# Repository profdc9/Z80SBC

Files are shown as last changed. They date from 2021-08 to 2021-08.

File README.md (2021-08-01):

# Z80 Single Board Computer

This is a PCB layout by Daniel Marks of Grant Searle's 9 chip CP/M computer as obtained from

http://searle.x10host.com/cpm/index.html

You need to follow his instructions on how to flash the memory and install CP/M.

http://searle.x10host.com/cpm/z80sbcFiles.zip

This design uses a 28C256 (32k X 8 EEPROM) rather than the original 27128 (16 x 8 EPROM).  JP6 needs to be set to the 16K setting, and only the first 16K of the EEPROM needs to be programmed.

I have added a 8255A peripheral interface and a SPI serial peripheral interface port.  I plan on modifying the SD card driver to use the faster hardware on this board, using the SD card loader here:

http://xepb.org/dtz/sgsbcsd.html

The SPI peripheral will hopefully allow other hardware to be easily added such as an ethernet interface (Wiznet or enc28j60) for TCP/IP, a SPI LCD for display, etc.  JP2 selects the clockspeed of the SPI, either 1/2 of 7.3278 MHz (slow clock) or 16 MHz (fast clock).

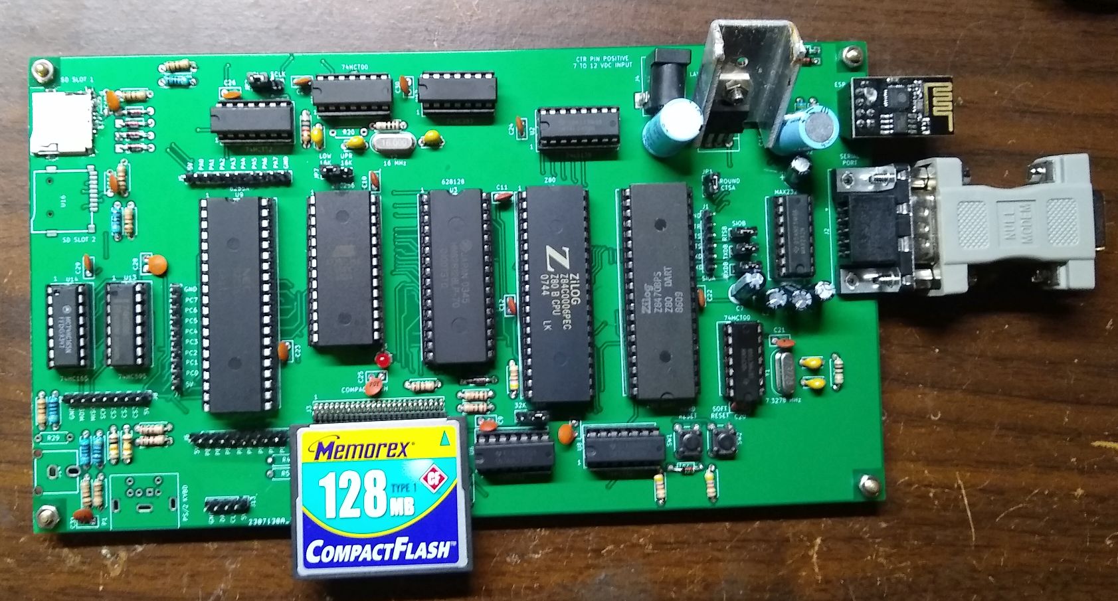
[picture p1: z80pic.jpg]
PCBphoto


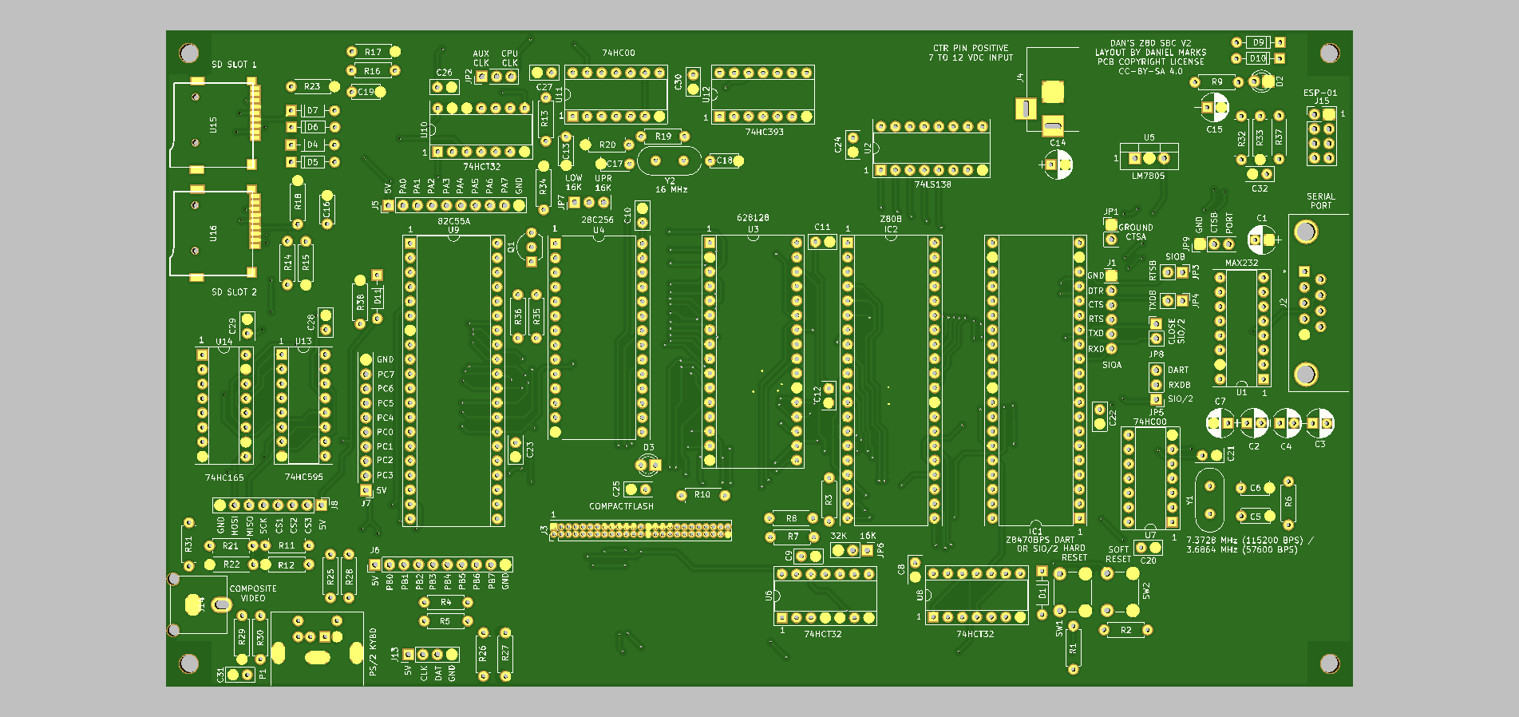
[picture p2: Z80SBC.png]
PCB


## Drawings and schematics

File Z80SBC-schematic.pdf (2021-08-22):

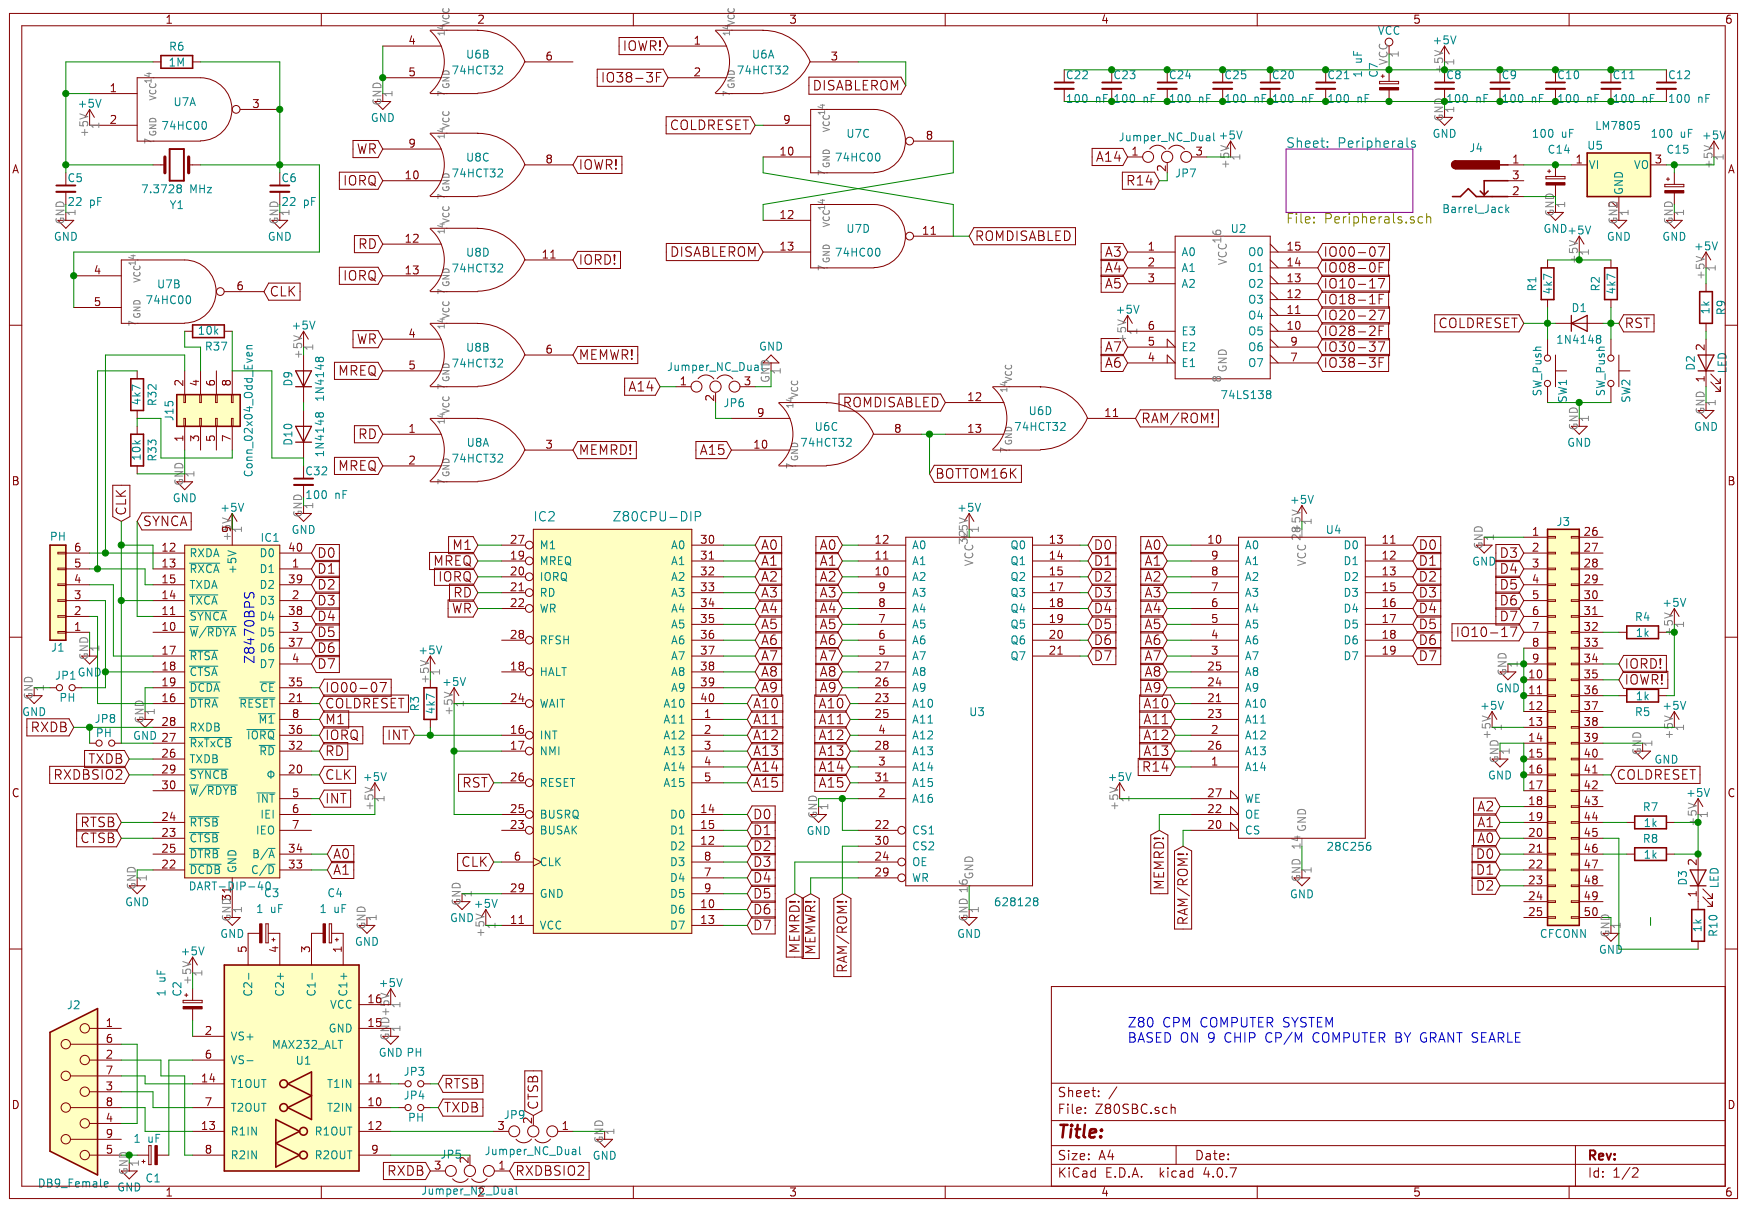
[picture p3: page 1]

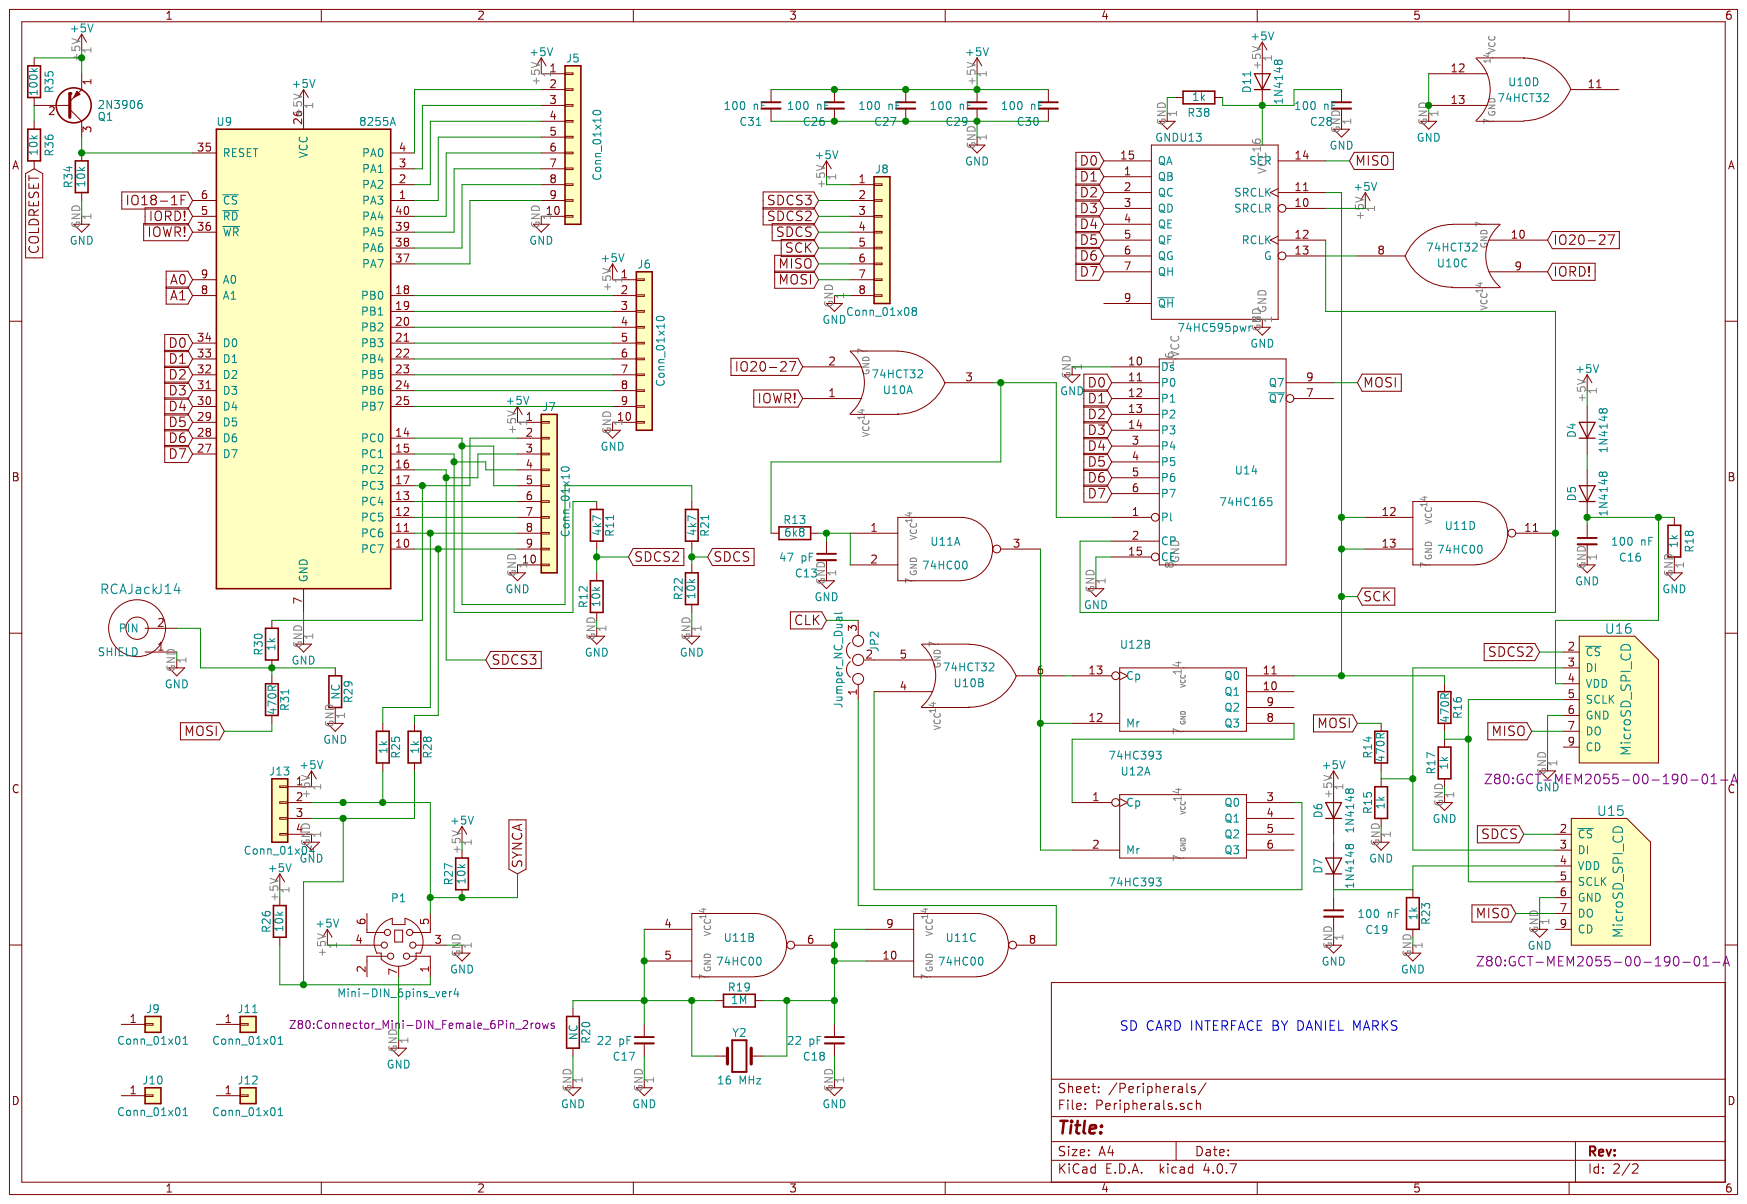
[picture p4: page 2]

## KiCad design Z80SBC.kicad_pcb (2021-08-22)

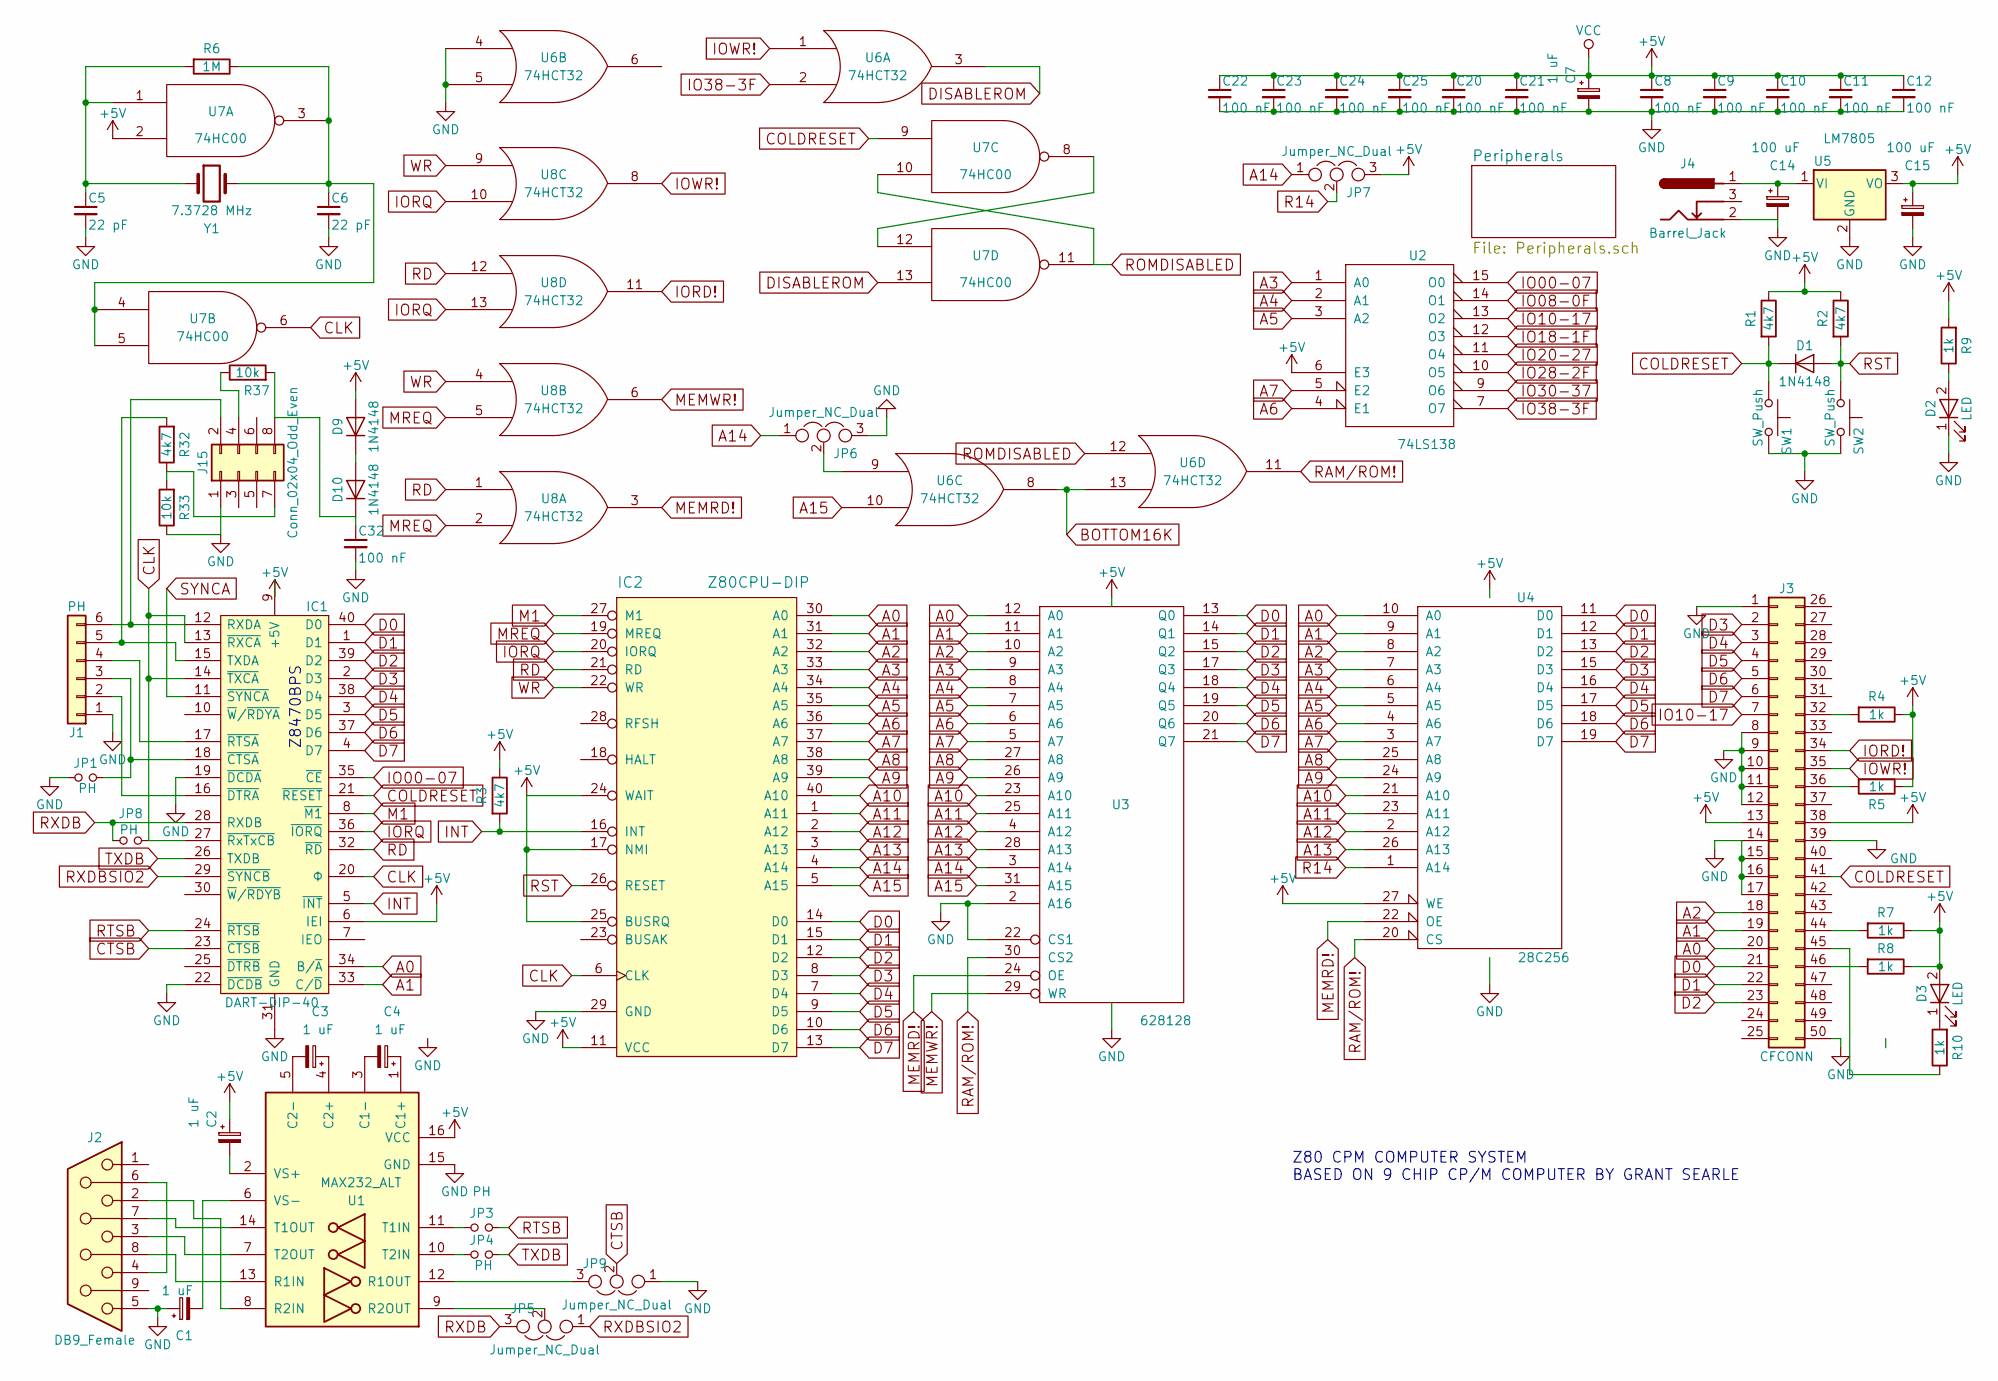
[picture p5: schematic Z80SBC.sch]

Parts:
C1, C2, C3, C4, C7: 1 uF; CP_Radial_D5.0mm_P2.50mm
C5, C6: 22 pF; C_Disc_D5.0mm_W2.5mm_P5.00mm
C8, C9, C10, C11, C12, C20, C21, C22, C23, C24, C25, C32: 100 nF; C_Disc_D5.0mm_W2.5mm_P2.50mm
C14, C15: 100 uF; CP_Radial_D5.0mm_P2.50mm
D1, D9, D10: 1N4148; D_DO-35_SOD27_P7.62mm_Horizontal
D2, D3: LED; LED_D3.0mm
IC1: DART-DIP-40; DIP-40_W15.24mm_Socket; Manufacturer_Part_Number Z84C4206PEG; Mouser Part Number 692-Z84C4206PEG
IC2: Z80CPU-DIP; DIP-40_W15.24mm_Socket
J1: PH; Pin_Header_Straight_1x06_Pitch2.54mm
J2: DB9_Female; DSUB-9_Female_Horizontal_P2.77x2.84mm_EdgePinOffset4.94mm_H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
J3: CFCONN; Pin_Header_Straight_2x25_Pitch1.27mm_Rev
J4: Barrel_Jack; BARREL_JACK
J15: Conn_02x04_Odd_Even; Pin_Header_Straight_2x04_Pitch2.54mm_Flipped
JP1, JP3, JP4, JP8: PH; Pin_Header_Straight_1x02_Pitch2.54mm
JP5, JP6, JP7, JP9: Jumper_NC_Dual; Pin_Header_Straight_1x03_Pitch2.54mm
R1, R2, R3, R32: 4k7; R_Axial_DIN0207_L6.3mm_D2.5mm_P7.62mm_Horizontal
R4, R5, R7, R8, R9, R10: 1k; R_Axial_DIN0207_L6.3mm_D2.5mm_P7.62mm_Horizontal
R6: 1M; R_Axial_DIN0207_L6.3mm_D2.5mm_P7.62mm_Horizontal
R33, R37: 10k; R_Axial_DIN0207_L6.3mm_D2.5mm_P7.62mm_Horizontal
SW1, SW2: SW_Push; SW_PUSH_6mm
U1: MAX232_ALT; DIP-16_W7.62mm_Socket
U2: 74LS138; DIP-16_W7.62mm_Socket
U3: 628128; DIP-32_W15.24mm_Socket
U4: 28C256; DIP-28_W15.24mm_Socket
U5: LM7805; TO-220-3_Vertical
U6, U8: 74HCT32; DIP-14_W7.62mm_Socket
U7: 74HC00; DIP-14_W7.62mm_Socket
Y1: 7.3728 MHz; Crystal_HC49-U_Vertical

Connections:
+5V: C2.1, C7.1, C8.1, C9.1, C10.1, C11.1, C12.1, C15.1, C20.1, C21.1, C22.1, C23.1, C24.1, C25.1, D3.2 (A), D9.2 (A), IC1.6 (IEI), IC1.9 (+5V), IC2.11 (VCC), IC2.17 (NMI), IC2.24 (WAIT), IC2.25 (BUSRQ), J3.13, J3.38, JP7.3, R1.1, R2.1, R3.1, R4.1, R5.1, R7.1, R8.1, R9.2, U1.16 (VCC), U2.6 (E3), U2.16 (VCC), U3.32 (VCC), U4.27 (WE), U4.28 (VCC), U5.3 (VO), U6.14 (VCC), U7.2, U7.14 (VCC), U8.14 (VCC); also elsewhere on the board
A0: IC1.34 (B/~A), IC2.30 (A0), J3.20, U3.12 (A0), U4.10 (A0); also elsewhere on the board
A1: IC1.33 (C/~D), IC2.31 (A1), J3.19, U3.11 (A1), U4.9 (A1); also elsewhere on the board
A2: IC2.32 (A2), J3.18, U3.10 (A2), U4.8 (A2)
A3: IC2.33 (A3), U2.1 (A0), U3.9 (A3), U4.7 (A3)
A4: IC2.34 (A4), U2.2 (A1), U3.8 (A4), U4.6 (A4)
A5: IC2.35 (A5), U2.3 (A2), U3.7 (A5), U4.5 (A5)
A6: IC2.36 (A6), U2.4 (E1), U3.6 (A6), U4.4 (A6)
A7: IC2.37 (A7), U2.5 (E2), U3.5 (A7), U4.3 (A7)
A8: IC2.38 (A8), U3.27 (A8), U4.25 (A8)
A9: IC2.39 (A9), U3.26 (A9), U4.24 (A9)
A10: IC2.40 (A10), U3.23 (A10), U4.21 (A10)
A11: IC2.1 (A11), U3.25 (A11), U4.23 (A11)
A12: IC2.2 (A12), U3.4 (A12), U4.2 (A12)
A13: IC2.3 (A13), U3.28 (A13), U4.26 (A13)
A14: IC2.4 (A14), JP6.1, JP7.1, U3.3 (A14)
A15: IC2.5 (A15), U3.31 (A15), U6.10
BOTTOM16K: U6.8, U6.13
CLK: IC1.13 (~RXCA), IC1.14 (~TXCA), IC1.20 (Φ), IC1.27 (~RxTxCB), IC2.6 (CLK), JP8.1, U7.6; also elsewhere on the board
COLDRESET: D1.1 (K), IC1.21 (~RESET), J3.41, R1.2, SW1.1, U7.9; also elsewhere on the board
CTSB: IC1.23 (~CTSB), JP9.2
D0: IC1.40 (D0), IC2.14 (D0), J3.21, U3.13 (Q0), U4.11 (D0); also elsewhere on the board
D1: IC1.1 (D1), IC2.15 (D1), J3.22, U3.14 (Q1), U4.12 (D1); also elsewhere on the board
D2: IC1.39 (D2), IC2.12 (D2), J3.23, U3.15 (Q2), U4.13 (D2); also elsewhere on the board
D3: IC1.2 (D3), IC2.8 (D3), J3.2, U3.17 (Q3), U4.15 (D3); also elsewhere on the board
D4: IC1.38 (D4), IC2.7 (D4), J3.3, U3.18 (Q4), U4.16 (D4); also elsewhere on the board
D5: IC1.3 (D5), IC2.9 (D5), J3.4, U3.19 (Q5), U4.17 (D5); also elsewhere on the board
D6: IC1.37 (D6), IC2.10 (D6), J3.5, U3.20 (Q6), U4.18 (D6); also elsewhere on the board
D7: IC1.4 (D7), IC2.13 (D7), J3.6, U3.21 (Q7), U4.19 (D7); also elsewhere on the board
DISABLEROM: U6.3, U7.13
GND: C1.1, C5.2, C6.2, C7.2, C8.2, C9.2, C10.2, C11.2, C12.2, C14.2, C15.2, C20.2, C21.2, C22.2, C23.2, C24.2, C25.2, C32.2, D2.1 (K), IC1.19 (~DCDA), IC1.22 (~DCDB), IC1.31 (GND), IC2.29 (GND), J1.1, J2.5, J3.1, J3.8, J3.9, J3.10, J3.11, J3.12, J3.14, J3.15, J3.16, J3.17, J3.39, J3.50, J4.2, J15.1, JP1.1, JP6.3, JP9.1, R33.1, SW1.2, SW2.2, U1.15 (GND), U2.8 (GND), U3.2 (A16), U3.16 (GND), U3.22 (CS1), U4.14 (GND), U5.2 (GND), U6.4, U6.5, U6.7 (GND), U7.7 (GND), U8.7 (GND); also elsewhere on the board
INT: IC1.5 (~INT), IC2.16 (INT), R3.2
IO00-07: IC1.35 (~CE), U2.15 (O0)
IO08-0F: U2.14 (O1)
IO10-17: J3.7, U2.13 (O2)
IO18-1F: U2.12 (O3); also elsewhere on the board
IO20-27: U2.11 (O4); also elsewhere on the board
IO28-2F: U2.10 (O5)
IO30-37: U2.9 (O6)
IO38-3F: U2.7 (O7), U6.2
IORD!: J3.34, U8.11; also elsewhere on the board
IORQ: IC1.36 (~IORQ), IC2.20 (IORQ), U8.10, U8.13
IOWR!: J3.35, U6.1, U8.8; also elsewhere on the board
M1: IC1.8 (~M1), IC2.27 (M1)
MEMRD!: U3.24 (OE), U4.22 (OE), U8.3
MEMWR!: U3.29 (WR), U8.6
MREQ: IC2.19 (MREQ), U8.2, U8.5
unnamed: C1.2, U1.6 (VS-)
unnamed: C2.2, U1.2 (VS+)
unnamed: C3.1, U1.4 (C2+)
unnamed: C3.2, U1.5 (C2-)
unnamed: C4.1, U1.1 (C1+)
unnamed: C4.2, U1.3 (C1-)
unnamed: C5.1, R6.2, U7.1, Y1.1
unnamed: C6.1, R6.1, U7.3, U7.4, U7.5, Y1.2
unnamed: C14.1, J4.1, U5.1 (VI)
unnamed: C32.1, D10.1 (K), J15.8, R37.2
unnamed: D2.2 (A), R9.1
unnamed: D3.1 (K), R10.2
unnamed: D9.1 (K), D10.2 (A)
unnamed: IC1.12 (RXDA), J1.6, J15.2
unnamed: IC1.15 (TXDA), J1.5, R32.2
unnamed: IC1.16 (~DTRA), J1.2
unnamed: IC1.17 (~RTSA), J1.4
unnamed: IC1.18 (~CTSA), J1.3, JP1.2
unnamed: J2.2, U1.8 (R2IN)
unnamed: J2.3, U1.7 (T2OUT)
unnamed: J2.4, J2.6
unnamed: J2.7, U1.14 (T1OUT)
unnamed: J2.8, U1.13 (R1IN)
unnamed: J3.32, R4.2
unnamed: J3.36, R5.2
unnamed: J3.44, R7.2
unnamed: J3.45, R10.1
unnamed: J3.46, R8.2
unnamed: J15.4, R37.1
unnamed: J15.7, R32.1, R33.2
unnamed: JP3.1, U1.11 (T1IN)
unnamed: JP4.1, U1.10 (T2IN)
unnamed: JP5.2, U1.9 (R2OUT)
unnamed: JP6.2, U6.9
unnamed: JP9.3, U1.12 (R1OUT)
unnamed: U7.8, U7.12
R14: JP7.2, U4.1 (A14)
RAM/ROM!: U3.30 (CS2), U4.20 (CS), U6.11
RD: IC1.32 (~RD), IC2.21 (RD), U8.1, U8.12
ROMDISABLED: U6.12, U7.10, U7.11
RST: D1.2 (A), IC2.26 (RESET), R2.2, SW2.1
RTSB: IC1.24 (~RTSB), JP3.2
RXDB: IC1.28 (RXDB), JP5.3, JP8.2
RXDBSIO2: IC1.29 (~SYNCB), JP5.1
SYNCA: IC1.11 (~SYNCA); also elsewhere on the board
TXDB: IC1.26 (TXDB), JP4.2
WR: IC2.22 (WR), U8.4, U8.9

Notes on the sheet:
Z80 CPM COMPUTER SYSTEM BASED ON 9 CHIP CP/M COMPUTER BY GRANT SEARLE
Z8470BPS

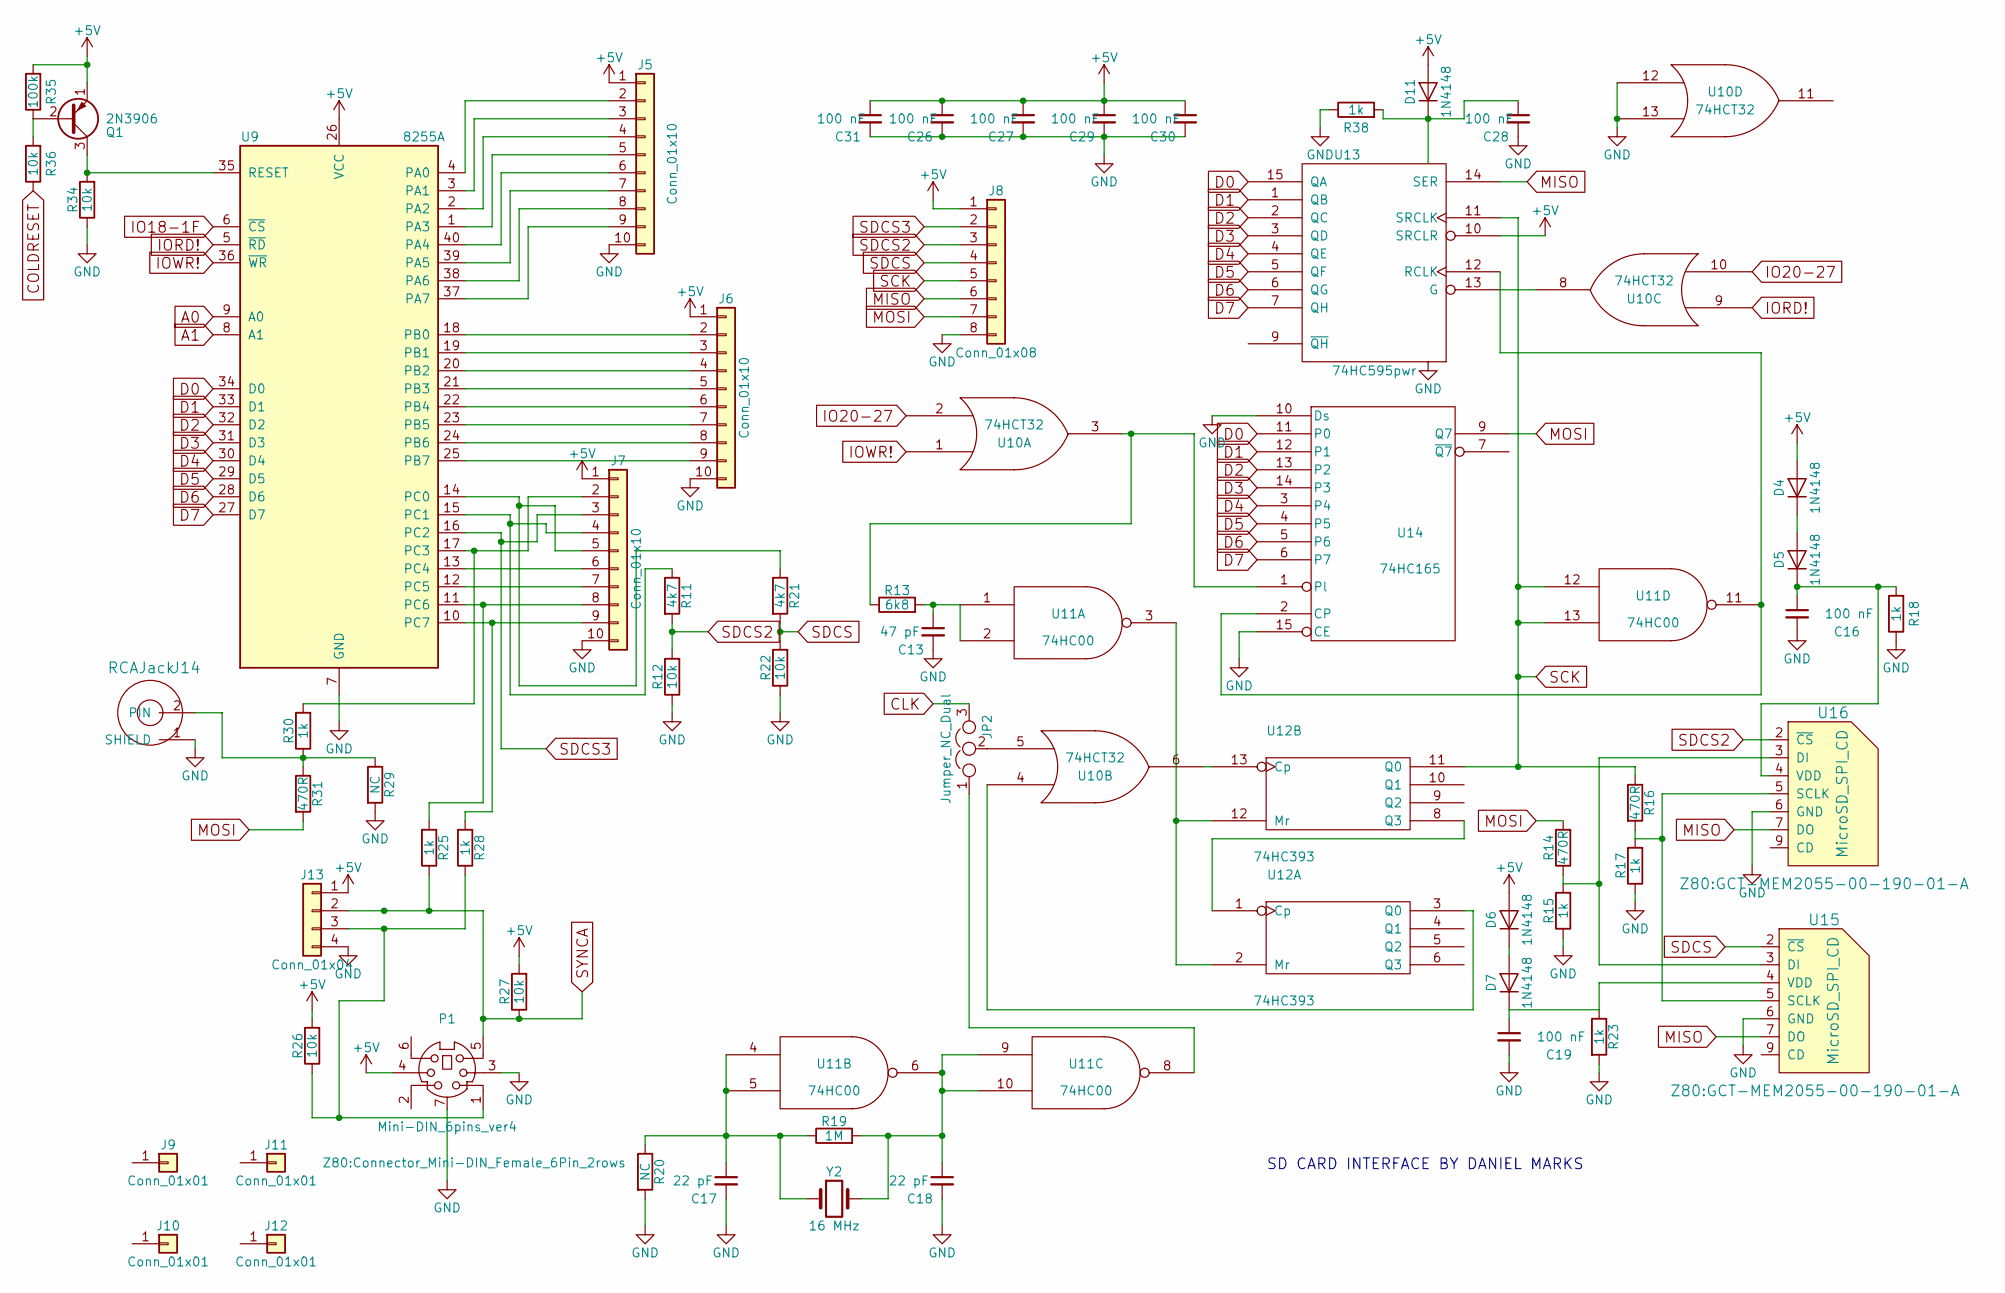
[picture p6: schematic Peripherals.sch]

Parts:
C13: 47 pF; C_Disc_D5.0mm_W2.5mm_P5.00mm
C16, C19: 100 nF; C_Disc_D5.0mm_W2.5mm_P5.00mm
C17, C18: 22 pF; C_Disc_D5.0mm_W2.5mm_P5.00mm
C26, C27, C28, C29, C30, C31: 100 nF; C_Disc_D5.0mm_W2.5mm_P2.50mm
D4, D5, D6, D7, D11: 1N4148; D_DO-35_SOD27_P7.62mm_Horizontal
J5, J6, J7: Conn_01x10; Pin_Header_Straight_1x10_Pitch2.54mm
J8: Conn_01x08; Pin_Header_Straight_1x08_Pitch2.54mm
J9, J10, J11, J12: Conn_01x01; MountingHole_3.2mm_M3
J13: Conn_01x04; Pin_Header_Straight_1x04_Pitch2.54mm
J14: RCAJack; RCAConnectorCommon
JP2: Jumper_NC_Dual; Pin_Header_Straight_1x03_Pitch2.54mm
P1: Mini-DIN_6pins_ver4; Connector_Mini-DIN_Female_6Pin_2rows
Q1: 2N3906; TO-92_Inline_Wide
R11, R21: 4k7; R_Axial_DIN0207_L6.3mm_D2.5mm_P7.62mm_Horizontal
R12, R22, R26, R27, R34, R36: 10k; R_Axial_DIN0207_L6.3mm_D2.5mm_P7.62mm_Horizontal
R13: 6k8; R_Axial_DIN0207_L6.3mm_D2.5mm_P7.62mm_Horizontal
R14, R16, R31: 470R; R_Axial_DIN0207_L6.3mm_D2.5mm_P7.62mm_Horizontal
R15, R17, R18, R23, R25, R28, R30, R38: 1k; R_Axial_DIN0207_L6.3mm_D2.5mm_P7.62mm_Horizontal
R19: 1M; R_Axial_DIN0207_L6.3mm_D2.5mm_P7.62mm_Horizontal
R20, R29: NC; R_Axial_DIN0207_L6.3mm_D2.5mm_P7.62mm_Horizontal
R35: 100k; R_Axial_DIN0207_L6.3mm_D2.5mm_P7.62mm_Horizontal
U9: 8255A; DIP-40_W15.24mm_Socket
U10: 74HCT32; DIP-14_W7.62mm_Socket
U11: 74HC00; DIP-14_W7.62mm_Socket
U12: 74HC393; DIP-14_W7.62mm_Socket
U13: 74HC595pwr
U14: 74HC165; DIP-16_W7.62mm_Socket
U15, U16: MicroSD_SPI_CD; GCT-MEM2055-00-190-01-A
Y2: 16 MHz; Crystal_HC49-U_Vertical

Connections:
+5V: C26.1, C27.1, C29.1, C30.1, C31.1, D4.2 (A), D6.2 (A), D11.2 (A), J5.1, J6.1, J7.1, J8.1, J13.1, P1.4, Q1.1 (E), R26.2, R27.2, R35.2, U9.26 (VCC), U10.14 (VCC), U11.14 (VCC), U12.14 (VCC), U13.10 (SRCLR), U14.16 (VCC); also elsewhere on the board
A0: U9.9 (A0); also elsewhere on the board
A1: U9.8 (A1); also elsewhere on the board
CLK: JP2.3; also elsewhere on the board
COLDRESET: R36.1; also elsewhere on the board
D0: U9.34 (D0), U13.15 (QA), U14.11 (P0); also elsewhere on the board
D1: U9.33 (D1), U13.1 (QB), U14.12 (P1); also elsewhere on the board
D2: U9.32 (D2), U13.2 (QC), U14.13 (P2); also elsewhere on the board
D3: U9.31 (D3), U13.3 (QD), U14.14 (P3); also elsewhere on the board
D4: U9.30 (D4), U13.4 (QE), U14.3 (P4); also elsewhere on the board
D5: U9.29 (D5), U13.5 (QF), U14.4 (P5); also elsewhere on the board
D6: U9.28 (D6), U13.6 (QG), U14.5 (P6); also elsewhere on the board
D7: U9.27 (D7), U13.7 (QH), U14.6 (P7); also elsewhere on the board
GND: C13.2, C16.2, C17.2, C18.2, C19.2, C26.2, C27.2, C28.2, C29.2, C30.2, C31.2, J5.10, J6.10, J7.10, J8.8, J13.4, J14.1 (SHIELD), P1.3, P1.7 (Shell), R12.1, R15.1, R17.1, R18.1, R20.2, R22.1, R23.2, R29.2, R34.1, R38.1, U9.7 (GND), U10.7 (GND), U10.12, U10.13, U11.7 (GND), U12.7 (GND), U13.8 (GND), U14.8 (GND), U14.10 (Ds), U14.15 (CE), U15.6 (GND), U16.6 (GND); also elsewhere on the board
IO18-1F: U9.6 (~CS~); also elsewhere on the board
IO20-27: U10.2, U10.10; also elsewhere on the board
IORD!: U9.5 (~RD~), U10.9; also elsewhere on the board
IOWR!: U9.36 (~WR~), U10.1; also elsewhere on the board
MISO: J8.6, U13.14 (SER), U15.7 (DO), U16.7 (DO)
MOSI: J8.7, R14.2, R31.2, U14.9 (Q7)
unnamed: C13.1, R13.2, U11.1, U11.2
unnamed: C16.1, D5.1 (K), R18.2, U16.4 (VDD)
unnamed: C17.1, R19.1, R20.1, U11.4, U11.5, Y2.1
unnamed: C18.1, R19.2, U11.6, U11.9, U11.10, Y2.2
unnamed: C19.1, D7.1 (K), R23.1, U15.4 (VDD)
unnamed: C28.1, D11.1 (K), R38.2, U13.16 (VCC)
unnamed: D4.1 (K), D5.2 (A)
unnamed: D6.1 (K), D7.2 (A)
unnamed: J5.2, U9.4 (PA0)
unnamed: J5.3, U9.3 (PA1)
unnamed: J5.4, U9.2 (PA2)
unnamed: J5.5, U9.1 (PA3)
unnamed: J5.6, U9.40 (PA4)
unnamed: J5.7, U9.39 (PA5)
unnamed: J5.8, U9.38 (PA6)
unnamed: J5.9, U9.37 (PA7)
unnamed: J6.2, U9.18 (PB0)
unnamed: J6.3, U9.19 (PB1)
unnamed: J6.4, U9.20 (PB2)
unnamed: J6.5, U9.21 (PB3)
unnamed: J6.6, U9.22 (PB4)
unnamed: J6.7, U9.23 (PB5)
unnamed: J6.8, U9.24 (PB6)
unnamed: J6.9, U9.25 (PB7)
unnamed: J7.2, R30.2, U9.17 (PC3)
unnamed: J7.4, R11.1, U9.15 (PC1)
unnamed: J7.5, R21.1, U9.14 (PC0)
unnamed: J7.6, U9.13 (PC4)
unnamed: J7.7, U9.12 (PC5)
unnamed: J7.8, R25.2, U9.11 (PC6)
unnamed: J7.9, R28.2, U9.10 (PC7)
unnamed: J13.3, P1.1, R26.1, R28.1
unnamed: J14.2 (PIN), R29.1, R30.1, R31.1
unnamed: JP2.1, U11.8
unnamed: JP2.2, U10.5
unnamed: Q1.2 (B), R35.1, R36.2
unnamed: Q1.3 (C), R34.2, U9.35 (RESET)
unnamed: R13.1, U10.3, U14.1 (Pl)
unnamed: R14.1, R15.2, U15.3 (DI), U16.3 (DI)
unnamed: R16.2, R17.2, U15.5 (SCLK), U16.5 (SCLK)
unnamed: U10.4, U12.3 (Q0)
unnamed: U10.6, U12.13 (Cp)
unnamed: U10.8, U13.13 (G)
unnamed: U11.3, U12.2 (Mr), U12.12 (Mr)
unnamed: U11.11, U13.12 (RCLK), U14.2 (CP)
unnamed: U12.1 (Cp), U12.8 (Q3)
SCK: J8.5, R16.1, U11.12, U11.13, U12.11 (Q0), U13.11 (SRCLK)
SDCS: J8.4, R21.2, R22.2, U15.2 (~CS)
SDCS2: J8.3, R11.2, R12.2, U16.2 (~CS)
SDCS3: J7.3, J8.2, U9.16 (PC2)
SYNCA: J13.2, P1.5, R25.1, R27.1; also elsewhere on the board

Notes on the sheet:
SD CARD INTERFACE BY DANIEL MARKS

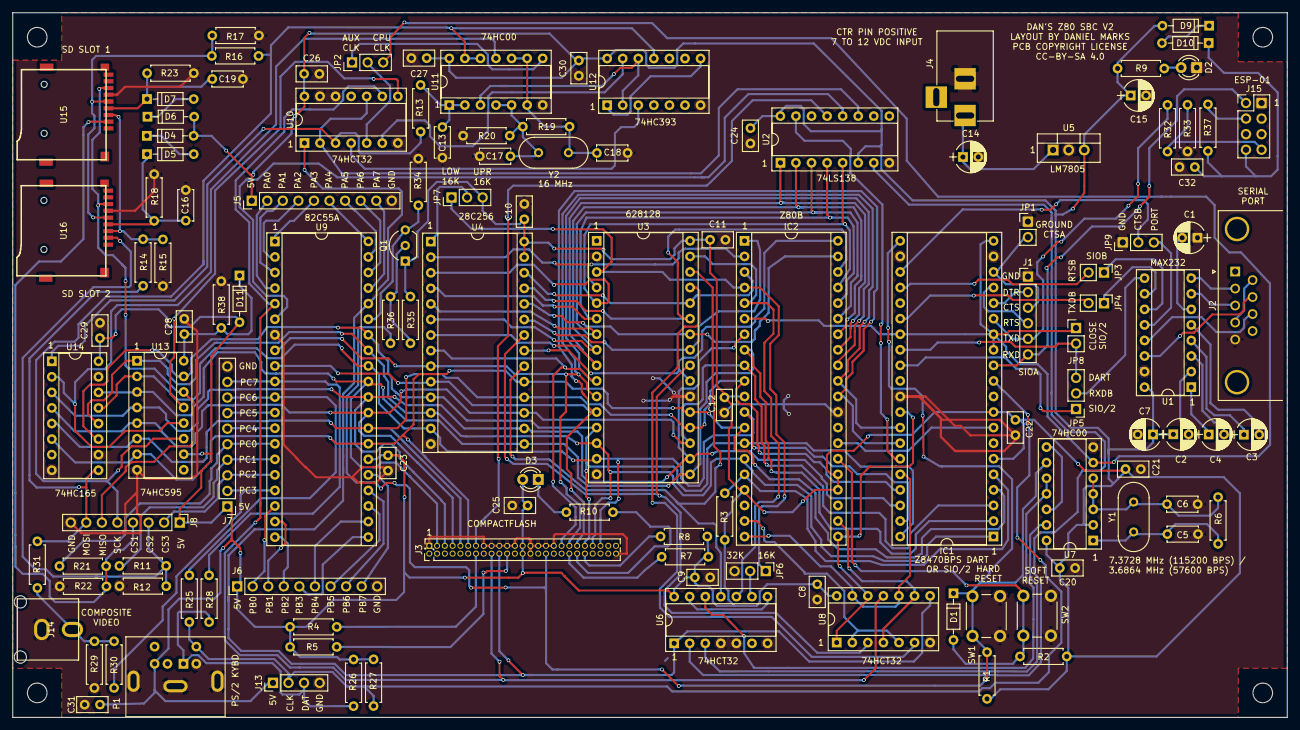
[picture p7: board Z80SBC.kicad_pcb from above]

Board: 2 copper layers, 208.0 x 115.0 mm, 127 parts (0 on the bottom side), 143 nets.

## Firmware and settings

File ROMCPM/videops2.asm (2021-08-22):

;------------------------------------------------------------------------------
;
; Z80 CP/M Video Demonstration
; by Daniel Marks

CTL8255 EQU     $1B
PTB8255 EQU     $19
SPIDPT  EQU     $20

STRT    ORG     $100
       
        JP      START

; Video Frame Buffer Defines

VIDFR   EQU     $2000       ; Location of frame buffer
VIDWDTH EQU     24          ; Number of bytes across in frame buffer (min 24)
VIDLN   EQU     246/2       ; Number of scan lines (246 for full, 246/2 for double lines)
VBLLN   EQU     16          ; Number of vertical blanking lines
VIDBYT  EQU     VIDWDTH*VIDLN   ; Number of bytes in frame bufer

DECFR   DB      0           ; The number of frames before leaving the video output loop
DECTL   DB      1           ; This is zero if stay in loop, or one if leave loop
                            ; always change DECFR before DECTL in interrupt
                            ; these are used to terminate the loop
CURCOL  DW      0           ; current offset for scrolling horizontally in framebuffer
FRAMEST DW      0           ; scratch for saving current framebuffer origin

; PS/2 Keyboard Defines

PS2STAT DB      0           ; Current state of PS2 keyboard driver in interrupt
PS2CC   DB      0           ; Current PS2 code being assembled by driver

PS2BUF  DS      8           ; Buffer size must be power of two
PS2BUFE EQU     $                     
PS2BITM EQU     (PS2BUFE-PS2BUF-1)   ; Bit mask for driver

PS2BUFI DB      0           ; Character being read out of FIFO buffer
PS2BUFO DB      0           ; Character beign written into FIFO buffer

; SIO control that we use for using the SIO interrupt for PS/2 keyboard interrupt

SIOA_D  EQU     $00
SIOA_C  EQU     $02
SIOB_D  EQU     $01
SIOB_C  EQU     $03

; Stuff for COM CP/M housekeeping

OLDSTK  DW      0            ; old stack pointer
NEWSTK  DS      64           ; new stack pointer
STOPSTK EQU     $-1
BDOS    EQU     5            ; CP/M BDOS call
SIOINTA EQU     $FFE0        ; Location of SIO interrupt pointer

MSGSTR  DB      13,10,"START PROGRAM",13,10,0
VIDMSG  DB      13,10,"CLEARED VIDEO",13,10,0

START   LD      HL,0
        ADD     HL,SP
        LD      (OLDSTK),HL     ; Save stack ptr
        LD      HL,STOPSTK      ; Use new stack
        LD      SP,HL
        LD      HL,MSGSTR
        CALL    OUTSTR          ; Display message
        CALL    INITVID         ; Initialize frame buffer
        CALL    INITPS2         ; Initialize PS/2 routine
        CALL    PS2INTS         ; Initialize interrupt and redirect
                                ; from CP/M BIOS
        LD      HL,VIDMSG       ; Say we initialized frame buffer
        CALL    OUTSTR
               
NL      CALL    GETPS2C
        OR      A
        JR      Z,NL2

        PUSH    AF
        LD      E,A         ; otherwise output using BDOS
        LD      C,2
        CALL    BDOS
        POP     AF
        JR      NL

NL2     LD      A,1             ; Set up to display 60 frames
        LD      (DECFR),A
        LD      A,60
        LD      (DECTL),A
        
        CALL    VIDEOF2         ; Call display function

        LD      A,(CURCOL)      ; Move scroll register to
        INC     A               ; pan display horizontally
        AND     $0f
        LD      (CURCOL),A

        LD      C,6        ; see if there is a key ready
        LD      E,$FF
        CALL    BDOS
        OR      A
        JP      Z,NL       ; if not, keep scrolling

        CALL    PS2INTD   ; Restore interrupt to CP/M BIOS

        LD      HL,(OLDSTK)    ; restore the stack
        LD      SP,HL          ; and leave
        RET
 
;  Outputs a string at HL

OUTSTR  PUSH    AF 
        PUSH    BC
        PUSH    DE
OUTL    LD      A,(HL)      ; Load a character
        OR      A           ; if zero quit
        JR      Z,OUTEX    
        LD      E,A         ; otherwise output using BDOS
        LD      C,2
        PUSH    HL
        CALL    BDOS
        POP     HL
        INC     HL          ; go to next character
        JP      OUTL
OUTEX   POP     DE
        POP     BC
        POP     AF
        RET
        
;  Initialize video frame buffer.  Fills it with a pattern
;  We force the SD card select lines high so that we don't accidentally
;  confuse the SD card with video data ! 
        
INITVID LD      A,$92           ; Configure port B as input, C as output
        OUT     (CTL8255),A
        LD      A,$3
        OUT     (CTL8255),A      ; Force SD card select lines high! 
        LD      A,$1
        OUT     (CTL8255),A
        LD      BC,VIDFR
        LD      HL,VIDBYT       ; Start at the top of buffer
CLRV    LD      A,C             ; Fill the buffer with a pattern
        AND     $7F
        ADD     A,B
        LD      (BC),A
        LD      A,$0
        INC     BC
        DEC     HL
        OR      H
        OR      L
        JP      NZ,CLRV         ; Keep going until the end
        RET
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

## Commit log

2021-04-15 With dual clock output
    [Z80SBC.kicad_pcb, Z80SBC.sch]
2021-04-19 Added README.md
    [Peripherals.sch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]
2021-04-19 revised README.md
    [Z80SBC.kicad_pcb, Z80SBC.sch]
2021-04-20 Added PS/2 keyboard input
    [Peripherals.sch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]
2021-04-29 Added ESP-01 and video output
    [Peripherals.sch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]
2021-08-01 Fixed jumpers, CF card position, ESP-01 enable
    [Peripherals.sch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]
2021-08-01 Schematic is back
2021-08-09 Added SD card driver
    [Peripherals.sch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]
2021-08-14 Fixed PS/2 interrupt line
    [Peripherals.sch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]
2021-08-17 Fixed SDHC support, added extra configuration jumpers
    [Peripherals.sch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]
2021-08-18 Modified video output
    [Peripherals.sch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]
2021-08-22 Moved around port B/C pins to separate input and output groups
    [Peripherals.sch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]

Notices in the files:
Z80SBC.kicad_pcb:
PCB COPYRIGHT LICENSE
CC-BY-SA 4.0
